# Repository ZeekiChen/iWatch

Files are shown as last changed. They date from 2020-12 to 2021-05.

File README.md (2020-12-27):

iWatch  
=====
# v1.1：  
## 主要配置：  
* 主控：STC8A8K64S4A12，64kROM，8kRAM，增强型51内核单片机  
* 屏幕：1.3寸单色OLED，128x64分辨率，驱动芯片ssd1315  
* 实时时钟：PCF863  
* USB转串口：CH340E  
* 加速度&角速度传感器：LSM6DSM  
* 地磁传感器：HMC5883L  
* 环境参数传感器：BME280  
* 数字收音机：RDA5807M  
* 蓝牙透传模块：PW02  
# v1.2：  
## 主要配置：  
* 主控：STC8A8K64S4A12，64kROM，8kRAM，增强型51内核单片机  
* 屏幕：1.3寸单色OLED，128x64分辨率，驱动芯片ssd1315  
* 实时时钟：PCF863  
* USB转串口：CH340E  
* 加速度&角速度传感器：LSM6DSM  
* 地磁传感器：LIS3MDL  
* 环境参数传感器：BME280  
* 蓝牙透传模块：RF-BM-4044B4  
## 制作建议：  
* `iWatch.pcbdoc`为主控板，建议板厚1mm  
* `iWatch-screen.pcbdoc`为屏幕板，建议板厚0.8mm  
* 主控板和屏幕板之间通过1.27mm间距插针连接，焊接上后不可拆卸，达到表身最小厚度  
* 主控板和屏幕板之间也可以通过1.27mm间距的排针排母进行连接，这样方便拆卸，但是表身厚度不能保证  
## 程序下载： 
* 在STC-ISP中设定运行频率为`24Mhz`  
* 设置用户EEPROM空间大小为`0.5k`  
相关问题交流讨论QQ群：659521788

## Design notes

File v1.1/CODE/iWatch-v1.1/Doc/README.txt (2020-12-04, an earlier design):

发布日期：2020-4-11
修改记录：
	2020-04-28
	1.修复了屏幕上方小白线的问题
	2.修复了计时器退出后记录清零的问题
	3.完善闹钟“特定一天”和“工作日”模式
	4.修复收音机无天线搜台自动复位问题
	5.修复了重力感应偶尔抽风的问题
	6.提升了指南针的精度
	7.取消了步数清零功能
	8.优化了开机速度
	9.优化了蓝牙初始化速度
	10.增加了蓝牙界面清屏提示
	11.修改了电池满电电压和放电截止电压
	12.修复了卡死的问题（有待验证）
	
	2020-07-02
	1.修复了闹钟响起引起的卡死问题（上次更新的第12条）
	2.修复了唤醒设备后时间显示不准确的问题
	3.修复了屏幕偶尔可能出现的上下颠倒问题
	4.修复了可能的复位设备后屏幕不显示的问题
	5.修复了计时器后台工作时停止计时的问题
	6.增加程序一键下载功能，点击下载器中的“下载/编程”
	  按键之后无需手动复位手表既可以下载程序
	7.下载时在STC-ISP中EEPROM大小选择0.5k（之前为1k）

	2020-11-10
	1.取消了上次更新里第6条的功能，因为该功能降低了手表的续航
	  更新此固件后手表下载程序需要手动复位

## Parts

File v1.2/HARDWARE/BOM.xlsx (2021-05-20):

Comment | Description | Designator | Footprint | Quantity
15pF | 贴片无极性电容 | C9 | C-0603-M | 1
0.1uF | 贴片无极性电容 | C1, C5, C8, C11, C12, C13, C17, C20 | C-0603-M | 8
1uF | 贴片无极性电容 | C2, C3, C7, C14, C15 | C-0603-M | 5
10uF | 贴片无极性电容 | C16, C18, C19 | C-0603-M | 3
1uF | 贴片有极性电容 | C10 | C-钽电容-3216-N | 1
10uF | 贴片有极性电容 | C6 | C-钽电容-3216-N | 1
47uF | 贴片有极性电容 | C4 | C-钽电容-3216-N | 1
0 | 贴片电阻 | R1 | R-0603-M | 1
22 | 贴片电阻 | R5 | R-0603-M | 1
330 | 贴片电阻 | R9 | R-0603-M | 1
1k | 贴片电阻 | R2, R6 | R-0603-M | 2
2k | 贴片电阻 | R3, R7, R8, R10, R11 | R-0603-M | 5
4.7k | 贴片电阻 | R4 | R-0603-M | 1
560k | 贴片电阻 | R12 | R-0603-M | 1
1N4148 | 高速开关二极管 | D1, D2 | SOD-323/0805 | 2
LED | 白光贴片LED | D3 | LED-0603 | 1
LED | 红光贴片LED | D4 | LED-0603 | 1
NMOS | N沟道场效应管 | Q1 | SOT-23 | 1
NPN | NPN型三极管 | Q2 | SOT-23 | 1
32.768khz | 无源晶振 | Y1 | FC135 | 1
Buzzer | 贴片蜂鸣器5020 | B1 | 蜂鸣器5020 | 1
MICRO USB | MICRO USB接口 | P1 | MICRO-USB-牛角插板-无卷边 | 1
MHDR1X3 | 1.27间距插针, 3-Pin | P2, P3 | MHDR1X3 | 2
MHDR1X15 | 1.27间距插针, 15-Pin | P7 | MHDR1X15 | 1
SS-12F23 | 1路波动开关 | S1 | MK-12C02 | 1
TSW | 3x6轻触开关 | SW1, SW2, SW3 | SB-2*4*3.5 | 3
STC8A8K64S4A12 | 增强型51单片机 | U1 | LQFP48 7X7 | 1
CH340E | USB转串口芯片，免外部晶振，超小封装 | U2 | MSOP10 | 1
TPS78233 | LDO-3.3v | U3 | SOT23-5 | 1
XT4054 | 锂电池充电ic | U4 | SOT23-5 | 1
LIS3MDL | 三轴磁力计 | U5 | LGA-12LD | 1
PCF8563 | 实时时钟 | U6 | TSSOP8_M | 1
LSM6DSM | always-on 3D accelerometer and 3D gyroscope | U7 | LGA-14L | 1
BME280 | 温度湿度压强一体式传感器 | U8 | LGA-8 | 1
RF-BM-4044B4 | 基于TI公司 CC2640R2F 芯片的低功耗蓝牙(BLE)射频模块 | M1 | RF-BM-4044B4 | 1
1.3"-128*64 | 单色1.3寸OLED裸屏，分辨率128x64，驱动SSD1316 | OLED | OLED-1.3-90 | 1
BAT-3.7v-302530 | 3.7v锂电池，尺寸302530 | BATTERY |  | 1

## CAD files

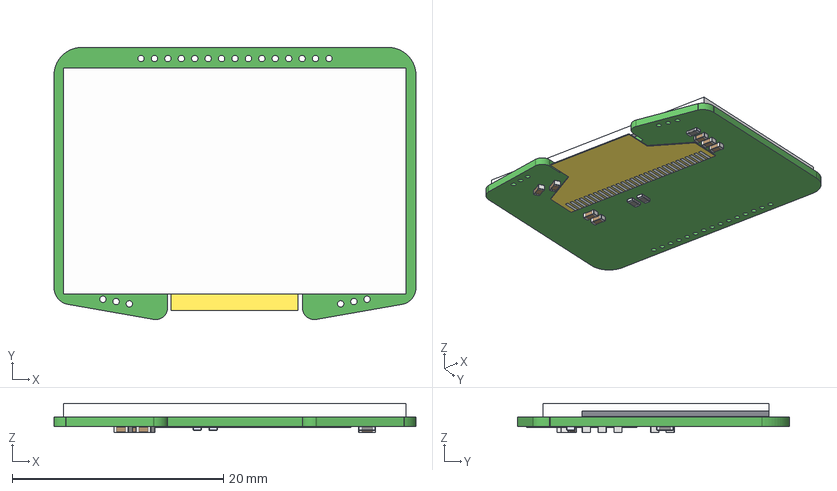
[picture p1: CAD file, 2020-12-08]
v1.2/HARDWARE/3DMODEL/iWatch-screen.step
34.3 x 25.8 x 2.77 mm
Board
Extruded x 35
RESC1608(0603) x 3
CAPC1608(0603) x 7

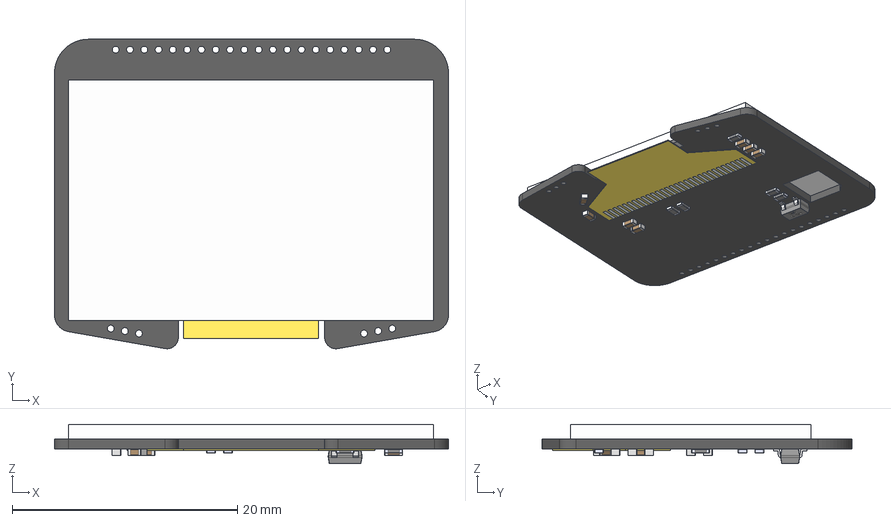
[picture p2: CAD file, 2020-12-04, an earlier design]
v1.1/HARDWARE/3DModel/iWatch-screen.step
35.0 x 27.5 x 3.47 mm
Board
RESC1608(0603) x 5
SOT-23
CAPC1608(0603) x 7
Extruded x 35

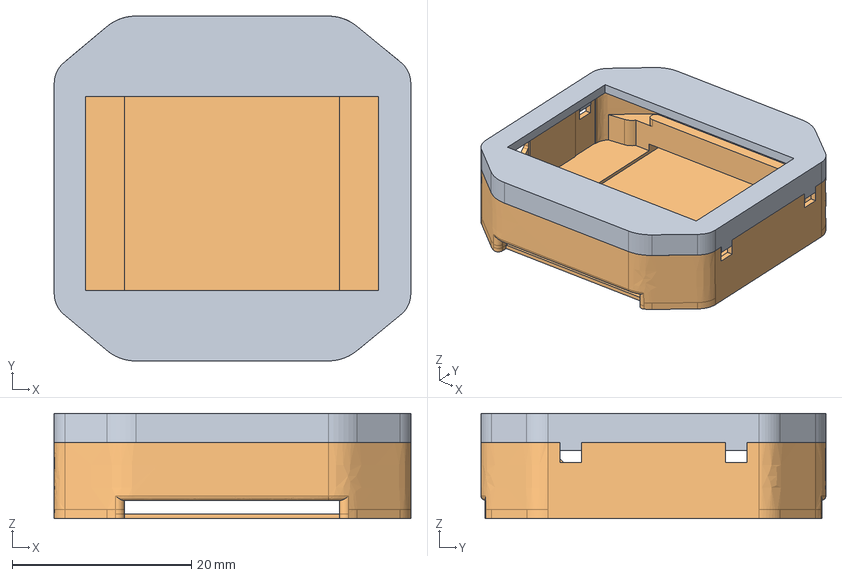
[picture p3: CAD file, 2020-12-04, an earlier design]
v1.1/HARDWARE/3DModel/上下壳.stp
39.8 x 38.5 x 11.8 mm

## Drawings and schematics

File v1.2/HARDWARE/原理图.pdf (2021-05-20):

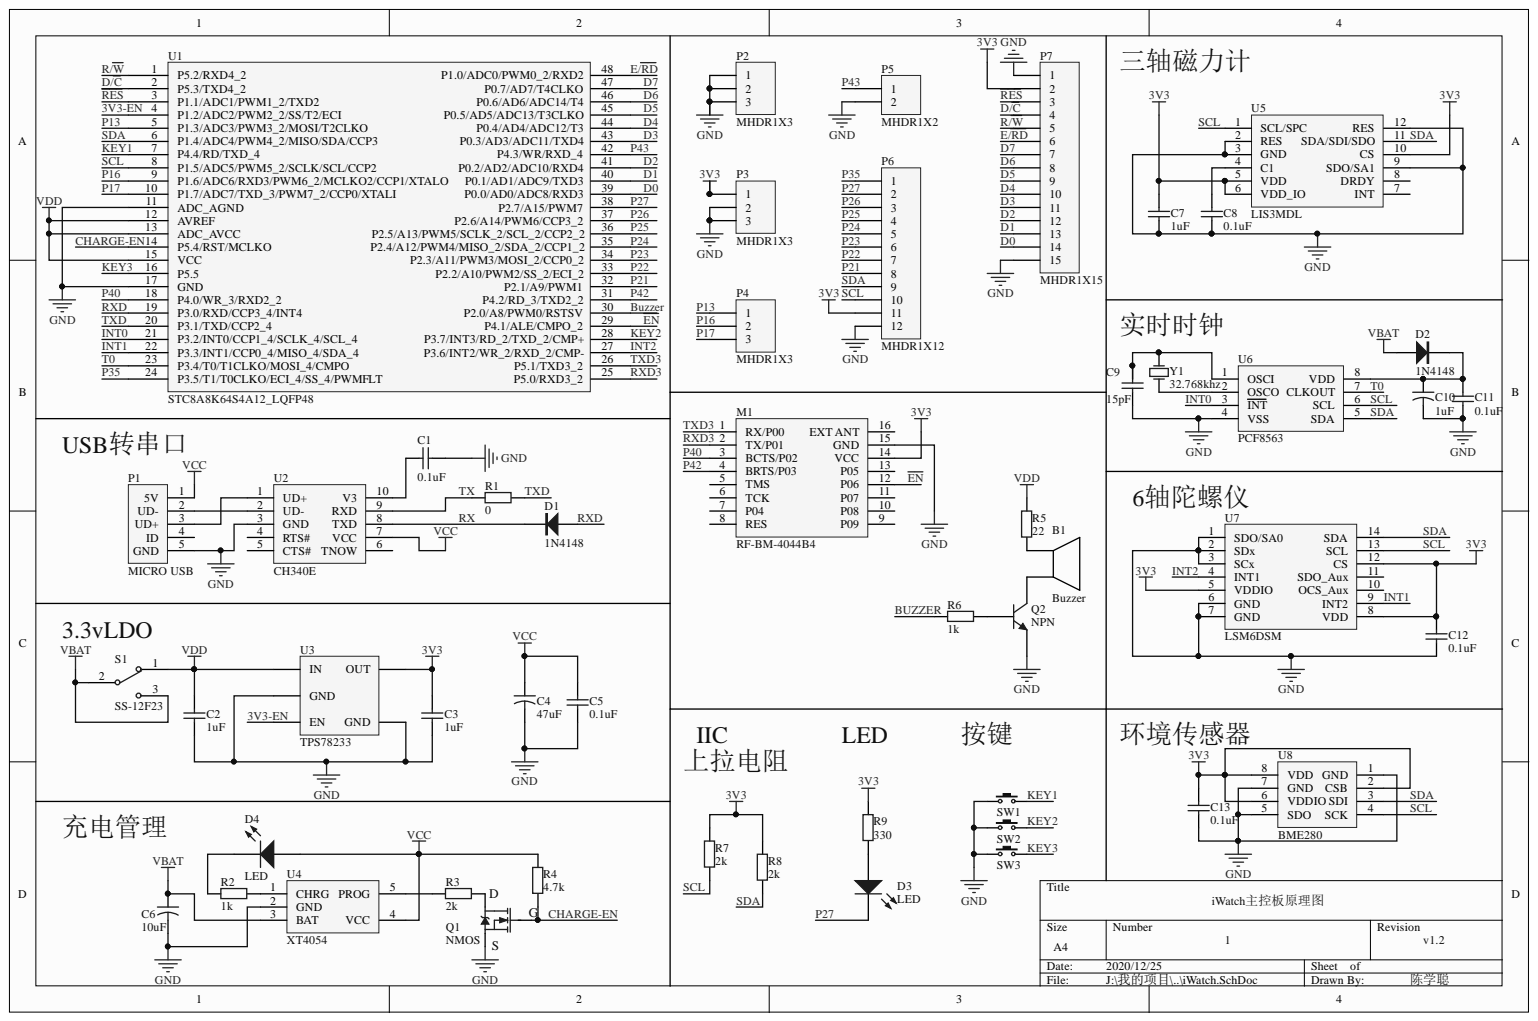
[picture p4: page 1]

7 | G N D CSB V D DIO SD I SD O SCK | 2

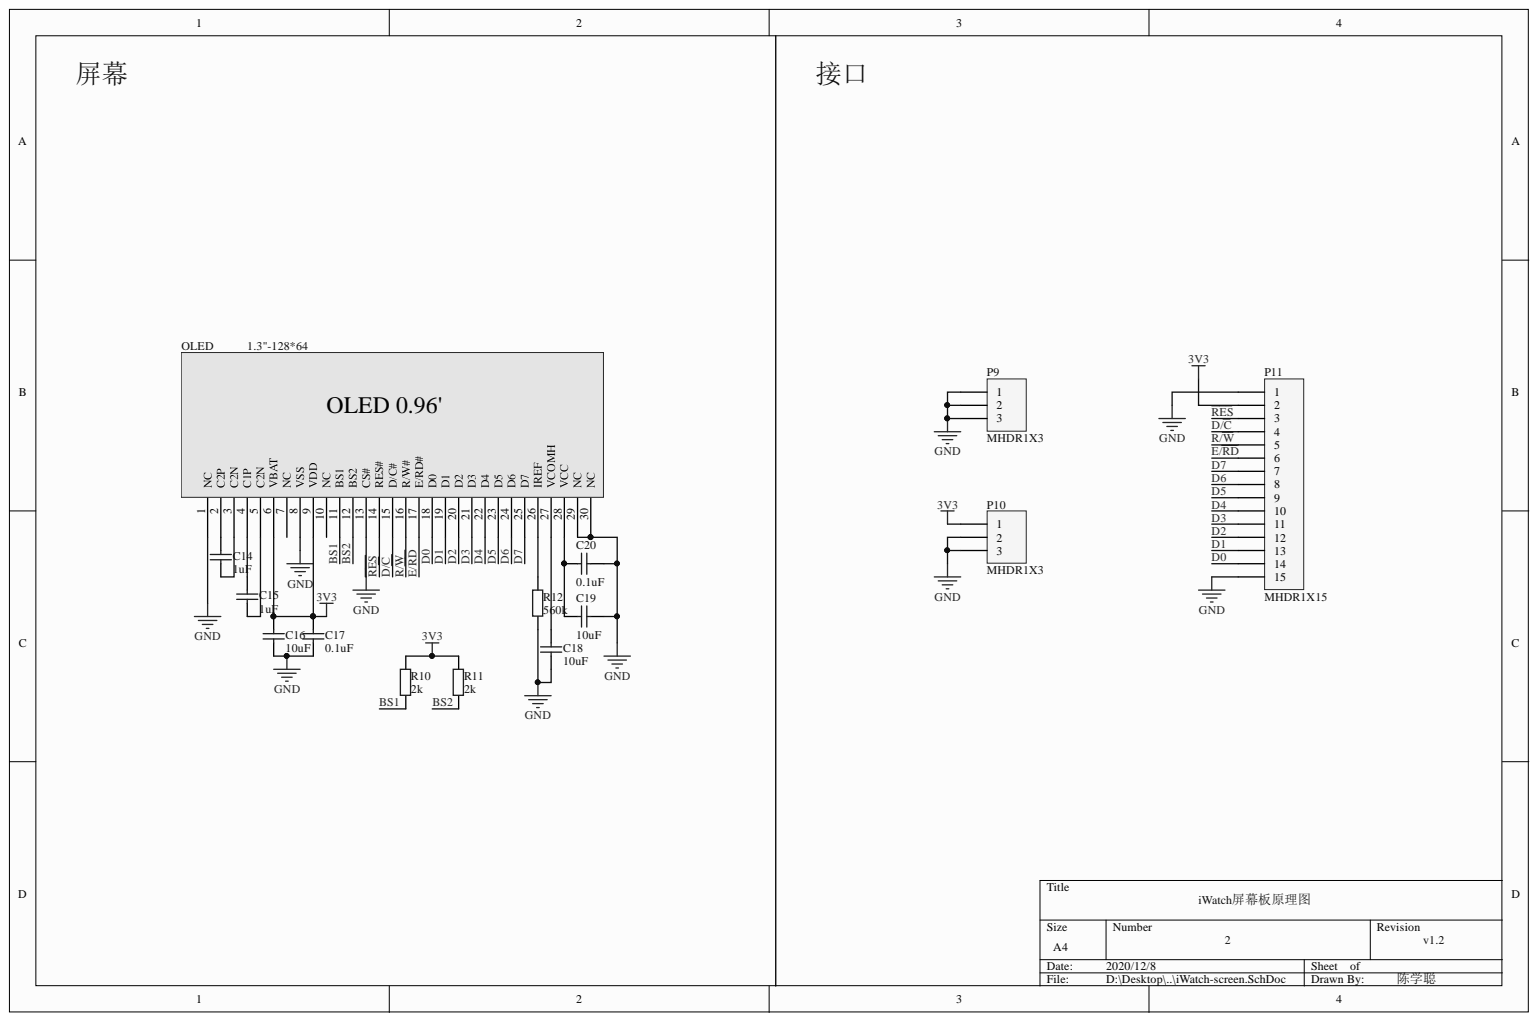
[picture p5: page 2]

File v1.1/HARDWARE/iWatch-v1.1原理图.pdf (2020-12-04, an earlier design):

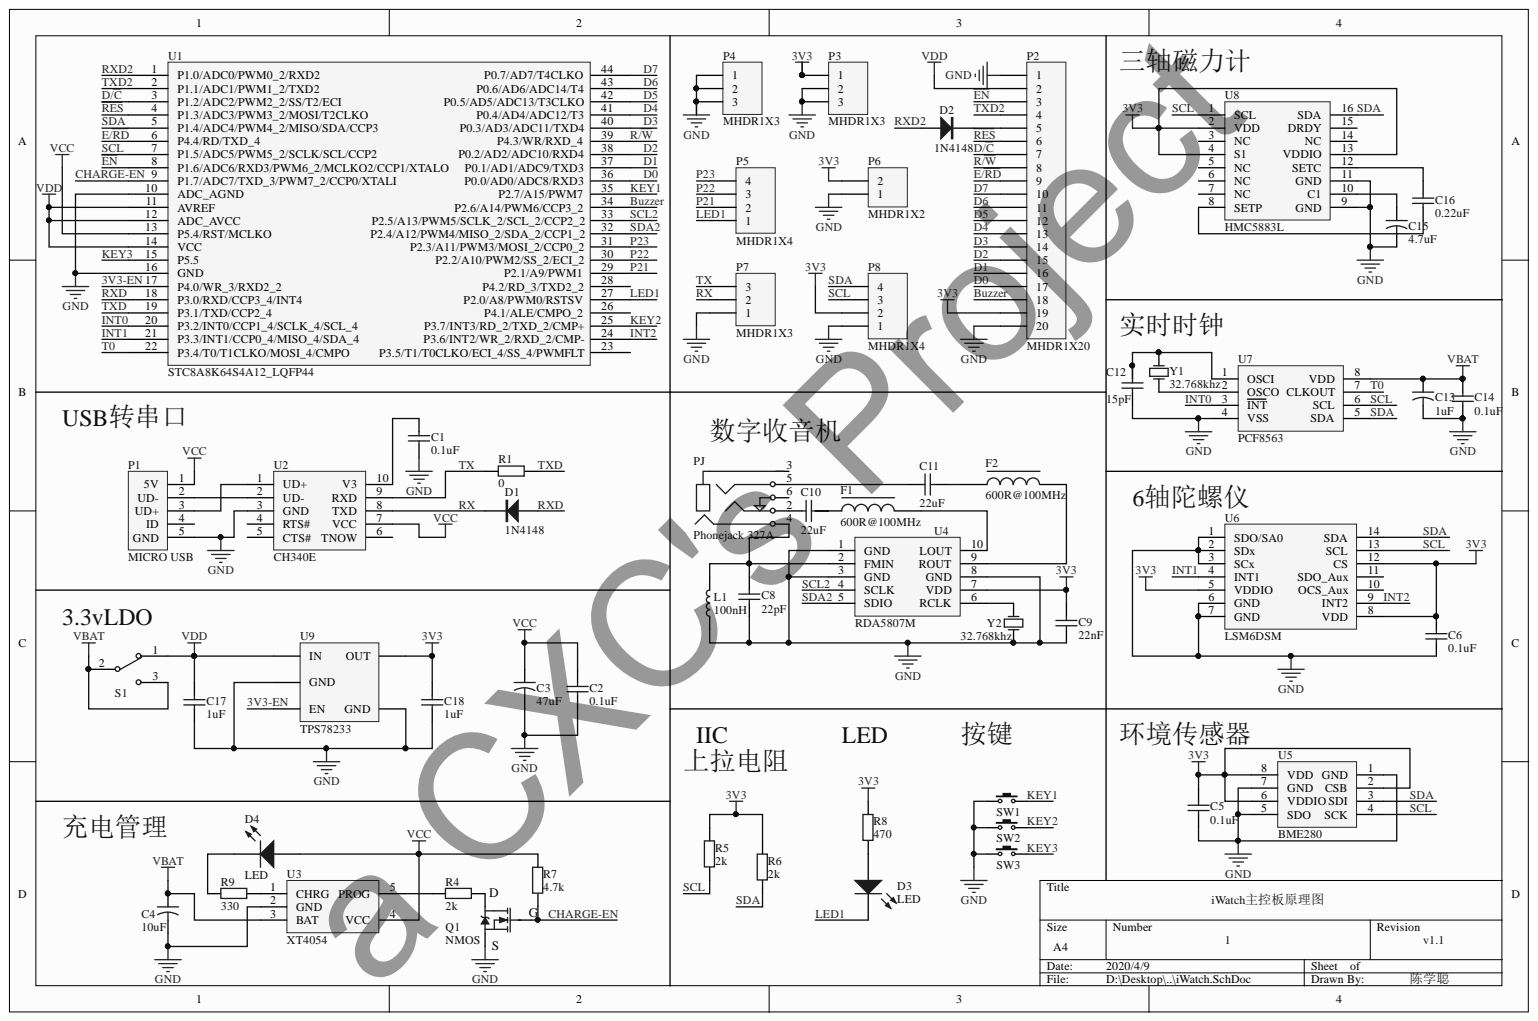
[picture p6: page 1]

GND 7 CSB SDI | 2
VDDIO 6 | 3

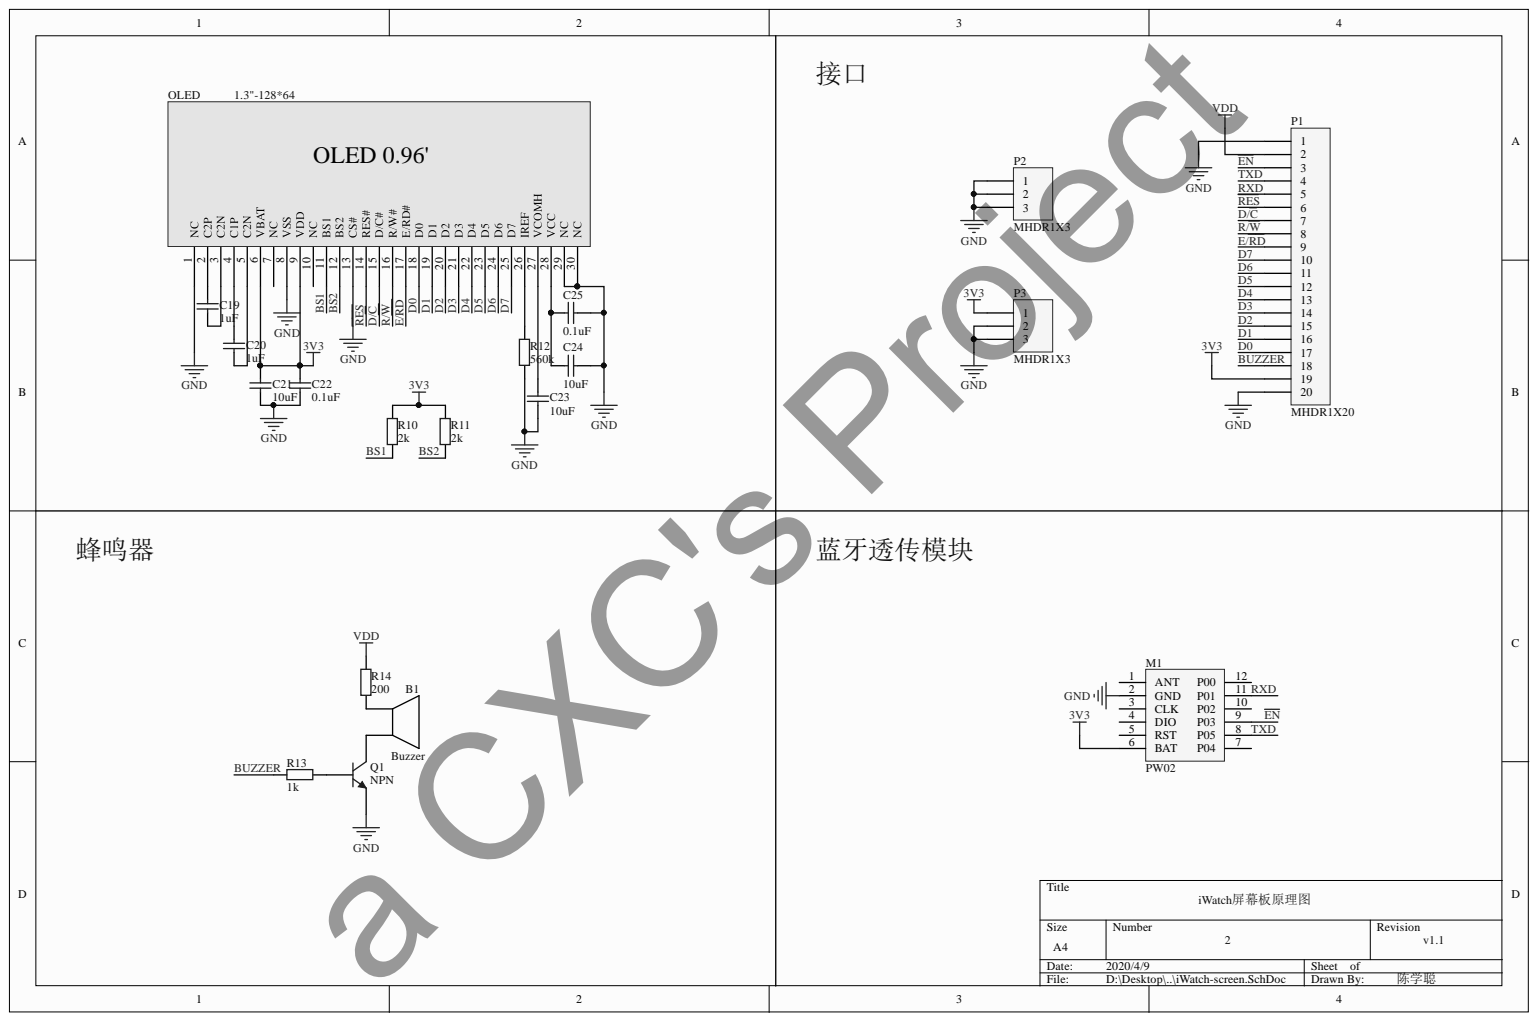
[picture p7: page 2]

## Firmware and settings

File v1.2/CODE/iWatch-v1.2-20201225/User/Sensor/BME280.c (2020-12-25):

#include "Sys.h"
#include "bme280.h"

//sbit CSB = P0^0;	//片选信号
//sbit SDO = P0^1;	//IIC地址增量，0：0xec， 1：0xee
/*************************补偿参数*****************************/
//补偿参数，每次上电后从BME280中读取一次即可
//Compensation Parameter for temperature
unsigned int	dig_T1;
int dig_T2, dig_T3;
//Compensation Parameter for pressure
unsigned int dig_P1;
int dig_P2, dig_P3, dig_P4, dig_P5, dig_P6, dig_P7, dig_P8, dig_P9;
//Compensation Parameter for humidity
unsigned char dig_H1, dig_H3;
int dig_H2, dig_H4, dig_H5;
char dig_H6;
long t_fine;
/*******************未补偿的传感器原始数据*********************/
unsigned long uncomp_pressure;
unsigned long uncomp_temperature;
unsigned int 	uncomp_humidity;
/**********************设置参数********************************/
//BME280测量模式。 0：休眠， 1/2：单次测量模式， 3：连续测量模式
unsigned char BME280_mode = 0;		//0:sleep mode, 1/2:forced mode, 3:normal mode
//超采样参数。 参数越大，数据噪声越小，动态响应越差，单次测量所需时间越长，为0时该参数的测量跳过
unsigned char osrs_h = 5, osrs_t = 5, osrs_p = 5;		//000: measurement skipped	001:oversampling x 1
																										//010: oversampling x 2			011:oversampling x 4
																										//100: oversampling x 8			101:oversampling x 16
//连续测量模式下，两次测量间隔的时间t_sb
unsigned char t_sb = 2;			//000:0.5ms		001:62.5ms		010:125ms
														//011:250ms		100:500ms			101:1000ms
														//110:10ms		111:20ms
//滤波系数
unsigned char filter = 4;		//000:filter off							001:filter coeffcient = 2
														//010:filter coeffcient = 4		011:filter coeffcient = 8
														//100:filter coeffcient = 16
unsigned char spi3w_en = 0;	//0:disable 3-wire SPI		1:enable 3-wire SPI
/***************************************************************************/

/**
  * @brief  使用IIC总线往BME280的寄存器中写一字节数据
  * @param  addr: 寄存器的地址
  * @param  dat: 	待写入的数据
  * @retval 无
  */
void BME280WriteByte(unsigned char addr, unsigned char dat)
{
	Single_WriteIIC(BME280_IIC_ADDR, addr, dat);
}
/**
  * @brief  使用IIC总线从BME280的寄存器中读一字节数据
  * @param  addr: 寄存器的地址
  * @retval 读出的一字节数据
  */
unsigned char BME280ReadByte(unsigned char addr)
{
	unsigned char temp;
	temp = Single_ReadIIC(BME280_IIC_ADDR,addr);
	return temp;
}
/**
  * @brief  检查与BME280的连接是否正常
  * @param  无
  * @retval 1（成功），0（失败）
  */
unsigned char BME280CheckConnection(void)
{
	if(BME280ReadByte(BME280_ID) == 0x60)
		return 1;
	else
		return 0;
}
/**
	* @brief 根据设置的参数来计算每次测量所需的最大时间
	* @param  无
	* @retval 毫秒单位的时间
	*/
unsigned int BME280_cal_meas_delay(void)
{
    unsigned char max_delay;
    unsigned char temp_osr;
    unsigned char pres_osr;
    unsigned char hum_osr;

    /*Array to map OSR config register value to actual OSR */
    unsigned char osr_sett_to_act_osr[] = { 0, 1, 2, 4, 8, 16 };

    /* Mapping osr settings to the actual osr values e.g. 0b101 -> osr X16  */
    if (osrs_t <= 5)
    {
        temp_osr = osr_sett_to_act_osr[osrs_t];
    }
    else
    {
        temp_osr = 16;
    }

    if (osrs_p <= 5)
    {
        pres_osr = osr_sett_to_act_osr[osrs_p];
    }
    else
    {
        pres_osr = 16;
    }

    if (osrs_h <= 5)
    {
        hum_osr = osr_sett_to_act_osr[osrs_h];
    }
    else
    {
        hum_osr = 16;
    }

    max_delay = (unsigned int)((1.25 + 2.3 * temp_osr) + (2.3 * pres_osr + 0.575) + (2.3 * hum_osr + 0.575));

    return max_delay;
}
/**
	* @brief 	从BME280中读取补偿参数
	*					每次重新上电后调用一次即可
	* @param  无
	* @retval 无
	*/
void BME280ReadCompensationParameter()
{
	unsigned char buf1[26], buf2[7];
	I2C_Read_MultiBytes(BME280_IIC_ADDR, CALIB00, 26, buf1);
	I2C_Read_MultiBytes(BME280_IIC_ADDR, CALIB26, 7, buf2);
	
	dig_T1 = (buf1[1] << 8) | buf1[0];
	dig_T2 = (buf1[3] << 8) | buf1[2];
	dig_T3 = (buf1[5] << 8) | buf1[4];
	dig_P1 = (buf1[7] << 8) | buf1[6];
	dig_P2 = (buf1[9] << 8) | buf1[8];
	dig_P3 = (buf1[11] << 8) | buf1[10];
	dig_P4 = (buf1[13] << 8) | buf1[12];
	dig_P5 = (buf1[15] << 8) | buf1[14];
	dig_P6 = (buf1[17] << 8) | buf1[16];
	dig_P7 = (buf1[19] << 8) | buf1[18];
	dig_P8 = (buf1[21] << 8) | buf1[20];
	dig_P9 = (buf1[23] << 8) | buf1[22];
	dig_H1 = buf1[25];
	dig_H2 = (buf2[1] << 8) | buf2[0];
	dig_H3 = buf2[2];
	dig_H4 = (buf2[3] << 4) | buf2[4];
	dig_H5 = (buf2[5] << 4) | (buf2[4] >> 4);
	dig_H6 = buf2[6];
}
/**
	* @brief 	从BME280中读取读传感器原始数据
	* @param  无
	* @retval 无
	*/
void BME280ReadSensorRawData(void)
{
	unsigned char buf[8];
	I2C_Read_MultiBytes(BME280_IIC_ADDR, PRESS_MSB, 8, buf);
	uncomp_pressure 	 = ((unsigned long)buf[0] << 12) | ((unsigned long)buf[1] << 4) | (buf[2] >> 4);
	uncomp_temperature = ((unsigned long)buf[3] << 12) | ((unsigned long)buf[4] << 4) | (buf[5] >> 4);
	uncomp_humidity 	 = ((unsigned int)buf[6] << 8) | buf[7];
}
/**
	* @brief This internal API is used to compensate the raw temperature data and
	* return the compensated temperature data in float data type.
	*/
float compensate_temperature(void)
{
	float var1;
  float var2;
  float temperature;
  float temperature_min = -40;
  float temperature_max = 85;

	var1 = ((float)uncomp_temperature) / 16384.0 - ((float)dig_T1) / 1024.0;
  var1 = var1 * ((float)dig_T2);
  var2 = (((float)uncomp_temperature) / 131072.0 - ((float)dig_T1) / 8192.0);
  var2 = (var2 * var2) * ((float)dig_T3);
  t_fine = (long)(var1 + var2);
  temperature = (var1 + var2) / 5120.0;
  if (temperature < temperature_min)
  {
		temperature = temperature_min;
  }
  else if (temperature > temperature_max)
  {
    temperature = temperature_max;
  }
	return temperature;
}
/**
	* @brief This internal API is used to compensate the raw pressure data and
	* return the compensated pressure data in float data type.
	*/
float compensate_pressure(void)
{
    float var1;
    float var2;
    float var3;
    float pressure;
    float pressure_min = 30000.0;
    float pressure_max = 110000.0;

    var1 = ((float)t_fine / 2.0) - 64000.0;
    var2 = var1 * var1 * ((float)dig_P6) / 32768.0;
    var2 = var2 + var1 * ((float)dig_P5) * 2.0;
    var2 = (var2 / 4.0) + (((float)dig_P4) * 65536.0);
    var3 = ((float)dig_P3) * var1 * var1 / 524288.0;
    var1 = (var3 + ((float)dig_P2) * var1) / 524288.0;
    var1 = (1.0 + var1 / 32768.0) * ((float)dig_P1);

    /* avoid exception caused by division by zero */
    if (var1 > (0.0))
    {
        pressure = 1048576.0 - (float) uncomp_pressure;
        pressure = (pressure - (var2 / 4096.0)) * 6250.0 / var1;
        var1 = ((float)dig_P9) * pressure * pressure / 2147483648.0;
        var2 = pressure * ((float)dig_P8) / 32768.0;
        pressure = pressure + (var1 + var2 + ((float)dig_P7)) / 16.0;
        if (pressure < pressure_min)
        {
            pressure = pressure_min;
        }
        else if (pressure > pressure_max)
        {
            pressure = pressure_max;
        }
    }
    else /* Invalid case */
    {
        pressure = pressure_min;
    }

    return pressure;
}
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

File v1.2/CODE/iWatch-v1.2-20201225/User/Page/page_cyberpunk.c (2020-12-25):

#include "iWatch.h"

extern unsigned char xdata main_cache[];
extern unsigned char xdata sub_cache[];

static PageExecuteRate_TypeDef Rate_50hz = {20, 0};

static unsigned char code Text[] = "CYBERPUNK2077";
static unsigned char code Icon[] = {
	0xFF,0xFF,0xFF,0xFF,0xFF,0xFF,0xFF,0xFF,0xFF,0xFF,0xFF,0xFF,0xFF,0xFF,0xFF,0xFF,
	0xFF,0xFF,0xFF,0xFF,0xFF,0xFF,0xFF,0xFF,0xFF,0xFF,0xFF,0xFF,0xFF,0xFF,0xFF,0xFF,
	0xFF,0xFF,0xFF,0xFF,0xFF,0xFF,0xFF,0xFF,0xFF,0xFF,0xFF,0xFF,0xFF,0xFF,0xFF,0xFF,
	0xFF,0xFF,0xFF,0xFF,0xFF,0xFF,0xFF,0xFF,0xFF,0xFF,0xFF,0xFF,0xFF,0xFF,0xFF,0xFF,
	0xFF,0xFF,0xFF,0xFF,0xFF,0xFF,0xFF,0xFF,0xFF,0xFF,0xFF,0xFF,0xFF,0xFF,0xFF,0xFF,
	0xFF,0xFF,0xFF,0xFF,0xFF,0xFF,0xFF,0xFF,0xFF,0xFF,0xFF,0xFF,0xFF,0xFF,0xFF,0xFF,
	0xFF,0xBF,0xBF,0x9F,0x8F,0x8F,0xB7,0x93,0x9B,0x9D,0x9C,0x4F,0x9F,0x2F,0x0F,0xA7,
	0xC9,0x0E,0xCF,0x8F,0xFF,0x9F,0x97,0x9F,0x4F,0x6F,0x6F,0x3F,0x8F,0xBF,0xDF,0x4F,
	0x67,0x37,0x5F,0x8F,0x3F,0x9F,0x2F,0xCF,0x9F,0x2F,0x77,0xFF,0xFB,0xFF,0xFF,0xFF,
	0xFF,0xFF,0xFF,0xFF,0xFF,0xFF,0xFF,0xFF,0xFF,0xFB,0xFD,0xFE,0xFF,0xFE,0xFF,0xFF,
	0xFF,0xFF,0xFF,0xFF,0xFE,0xF7,0xFF,0xFF,0xFF,0xF7,0xF9,0xFF,0xFF,0xF7,0xFF,0xFE,
	0xFF,0xFF,0xFF,0xFF,0xFF,0xFF,0xFF,0xFF,0xFF,0xFF,0xFF,0xFE,0xFD,0xFB,0xFF,0xFF,
	0xFF,0xFF,0xFF,0xFF,0xFF,0xFF,0xFF,0xFF,0xFF,0xFF,0xFF,0xFF,0xFF,0xFF,0xFF,0xFF,
	0xFF,0xFF,0xFF,0xFF,0xFF,0xFF,0xFF,0xFF,0xFF,0xFF,0xFF,0xFF,0xFF,0xFF,0xFF,0xFF,
	0xFF,0xFF,0xFF,0xFF,0xFF,0xFF,0xFF,0xFF,0xFF,0xFF,0xFF,0xFF,0xFF,0xFF,0xFF,0xFF,
	0x3F,0x3F,0x3F,0xFF,0xFF,0xFF,0xFF,0xFF,0xFF,0xFF,0xFF,0xFF,0xFF,0xFF,0xFF,0xFF,
	0xFF,0xFF,0xFF,0xFF,0xFF,0xFF,0xFF,0xFF,0xFF,0xFF,0xFF,0xFF,0xFF,0xFF,0xFF,0xFF,
	0xFF,0xFF,0xFF,0xFF,0xFF,0xFF,0xFF,0xFF,0xFF,0xFF,0xFF,0xFF,0xFF,0xFF,0xFF,0xFF
	/* (48 X 48 )*/
};

static unsigned int rx_buf_num = 0;
bit frame_received_flag = 0;
bit serial_busy = 0;
void UartInit_1(void)		//576000bps@24.000MHz
{
	SCON = 0x50;		//8???,?????
	AUXR |= 0x40;		//???1???Fosc,?1T
	AUXR &= 0xFE;		//??1?????1???????
	TMOD &= 0x0F;		//?????1?16???????
	TL1 = 0xF6;		//??????
	TH1 = 0xFF;		//??????
	ET1 = 0;		//?????1??
	TR1 = 1;		//?????1
	ES = 1;					//开串口中断
	TI = 0;
	RI = 0;
}
void UART1_Isr() interrupt 4 using 1
{
	if(RI)
	{
		RI = 0;
		main_cache[rx_buf_num++] = SBUF;
		if(rx_buf_num == 1024)
		{
			rx_buf_num = 0;
			frame_received_flag = 1;
		}
	}
	if(TI)
	{
		TI = 0;
		serial_busy = 0;
	}
}
void UART1SendString(char *str)
{
	while(*str)
  {
		while(serial_busy);
		serial_busy = 1;
		SBUF = *str++;
  }
}
void StartFrameReceive()
{
	UART1SendString("ok");
	frame_received_flag = 0;
	rx_buf_num = 0;
}
/**
  * @brief  页面初始化事件
  * @param  无
  * @retval 无
  */
static void Setup()
{
	ClearCache(sub_cache);
	ShowString(12, 2, "PRESS KEY2 TO", sub_cache, FONT8X16, NO_INVERSED);
	ShowString(44, 4, "START", sub_cache, FONT8X16, NO_INVERSED);
	UartInit_1();
	PageOpenAnim(ANIM_RIGHT);
}
/**
  * @brief  页面退出事件
  * @param  无
  * @retval 无
  */
static void Exit()
{
	UartInit();
	PageCloseAnim(ANIM_RIGHT);
}
/**
  * @brief  页面循环执行的内容
  * @param  无
  * @retval 无
  */
static void Loop()
{
	iWatchKeepActive();
	if(frame_received_flag)
	{
		OLED_Refresh(main_cache);
		StartFrameReceive();
	}
}
/**
  * @brief  页面事件
  * @param  btn:发出事件的按键
  * @param  event:事件编号
  * @retval 无
  */
static void Event(unsigned char event)
{
	if(event == KEY1)
		PageShift(page_menu);
	else if(event == KEY2)
		StartFrameReceive();
}

void PageRegister_page_cyberpunk(unsigned char pageID)
{
	PageRegister(pageID, Text, Icon, Setup, Loop, Exit, Event);
}
